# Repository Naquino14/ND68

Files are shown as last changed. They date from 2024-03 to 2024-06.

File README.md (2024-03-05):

# ND68
**ND68 MKL (Most keyless) Proto**
ND68 3
ND68 is a quest to design a custom 68% keyboard pcb powered by an RP2040, complete with per key RGB, hot-swappable keys, and a USB-C connector. 
We are in the prototyping phase, and if successful the prototype works as a macro pad. 
ND68 4

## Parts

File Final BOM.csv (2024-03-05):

# | QUANTITY | PART NUMBER | MANUFACTURER PART NUMBER | DESCRIPTION | CUSTOMER REFERENCE | BACKORDER | UNIT PRICE | EXTENDED PRICE
1 | 10 | 1276-1096-1-ND | CL21A106KOQNNNE | CAP CER 10UF 16V X5R 0805 |  | 0 | 0.07 | 0.7
2 | 10 | 490-13339-1-ND | GRM155R70J105KA12J | CAP CER 1UF 6.3V X7R 0402 |  | 0 | 0.035 | 0.35
3 | 50 | 1276-1013-1-ND | CL03A104KQ3NNNC | CAP CER 0.1UF 6.3V X5R 0201 |  | 0 | 0.008 | 0.4
4 | 10 | 490-9658-1-ND | GRM0335C1E150JA01D | CAP CER 15PF 25V C0G/NP0 0201 |  | 0 | 0.011 | 0.11
5 | 142 | 4878-1N4148WCT-ND | 1N4148W | DIODE GEN PURP 75V 150MA SOD123F |  | 0 | 0.0378 | 5.37
6 | 3 | 2073-USB4105-GF-ACT-ND | USB4105-GF-A | CONN RCP USB2.0 TYP C 24P SMD RA |  | 0 | 0.81 | 2.43
7 | 10 | 311-5.10KHRCT-ND | RC0603FR-075K1L | RES 5.1K OHM 1% 1/10W 0603 |  | 0 | 0.019 | 0.19
8 | 10 | 311-1.0KJRCT-ND | RC0402JR-071KL | RES 1K OHM 5% 1/16W 0402 |  | 0 | 0.018 | 0.18
9 | 10 | YAG3085CT-ND | RC0402FR-0727R4L | RES 27.4 OHM 1% 1/16W 0402 |  | 0 | 0.015 | 0.15
10 | 3 | CKN12310-1-ND | PTS636 SM43 SMTR LFS | SWITCH TACTILE SPST-NO 0.05A 12V |  | 0 | 0.19 | 0.57
11 | 3 | 488-NCP1117IST33T3GCT-ND | NCP1117IST33T3G | LDO REGULATOR, 1 A, FIXED AND AD |  | 0 | 0.62 | 1.86
12 | 3 | 2648-SC0914(13)CT-ND | SC0914(13) | IC MCU 32B EXT MEM 56QFN RP2040 |  | 0 | 0.7 | 2.1
13 | 3 | W25Q128JVSIQ-ND | W25Q128JVSIQ | IC FLASH 128MBIT SPI/QUAD 8SOIC |  | 0 | 1.73 | 5.19
14 | 3 | 535-9826-1-ND | ABM8-12.000MHZ-B2-T | CRYSTAL 12.0000MHZ 18PF SMD |  | 0 | 0.55 | 1.65
15 | 1 | PEC11R-4215F-S0024-ND | PEC11R-4215F-S0024 | ROTARY ENCODER MECHANICAL 24PPR |  | 0 | 2.12 | 2.12

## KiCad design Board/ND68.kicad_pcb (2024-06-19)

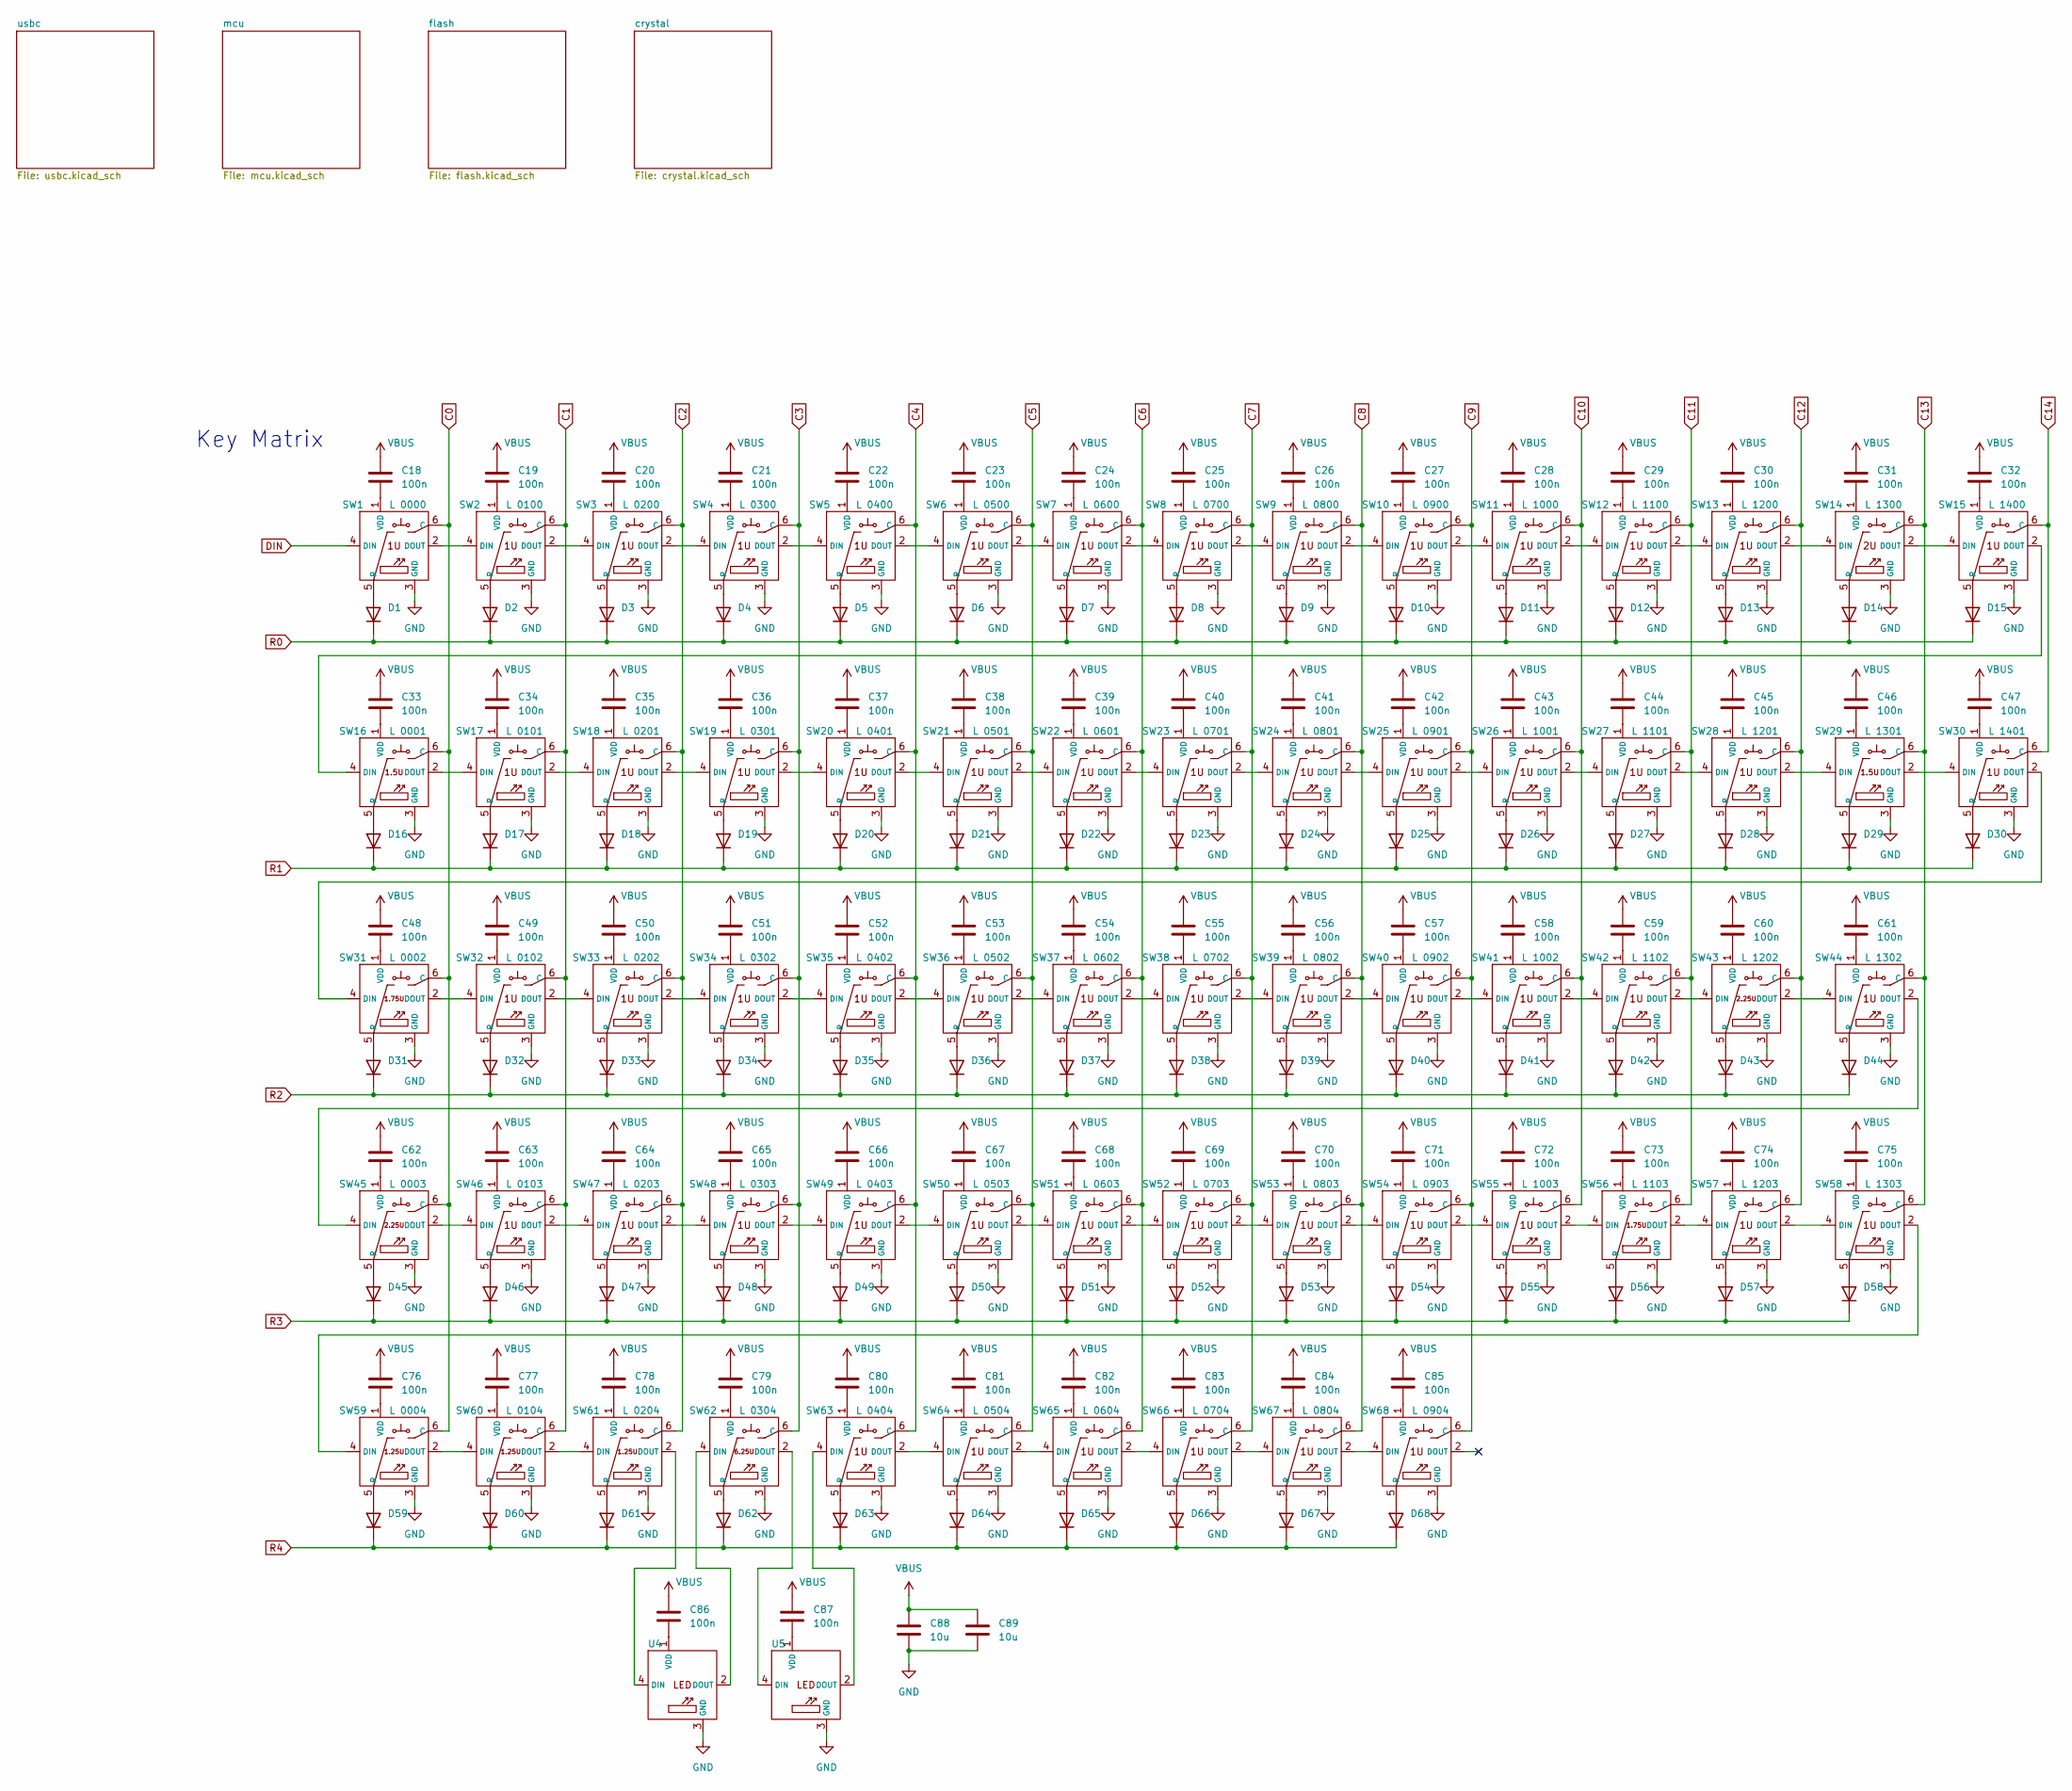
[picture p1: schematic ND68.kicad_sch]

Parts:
C18, C19, C20, C21, C22, C23, C24, C25, C26, C27, C28, C29, C30, C31, C32, C33, C34, C35, C36, C37, C38, C39, C40, C41, C42, C43, C44, C45, C46, C47, C48, C49, C50, C51, C52, C53, C54, C55, C56, C57, C58, C59, C60, C61, C62, C63, C64, C65, C66, C67, C68, C69, C70, C71, C72, C73, C74, C75, C76, C77, C78, C79, C80, C81, C82, C83, C84, C85, C86, C87: 100n; C_0603_1608Metric; DigiKey 311-1088-2-ND
C88, C89: 10u; C_0805_2012Metric; DigiKey 1276-1096-1-ND
D1, D2, D3, D4, D5, D6, D7, D8, D9, D10, D11, D12, D13, D14, D15, D16, D17, D18, D19, D20, D21, D22, D23, D24, D25, D26, D27, D28, D29, D30, D31, D32, D33, D34, D35, D36, D37, D38, D39, D40, D41, D42, D43, D44, D45, D46, D47, D48, D49, D50, D51, D52, D53, D54, D55, D56, D57, D58, D59, D60, D61, D62, D63, D64, D65, D66, D67, D68: D; D_SOD-123F; DigiKey 4878-1N4148WCT-ND
SW1, SW2, SW3, SW4, SW5, SW6, SW7, SW8, SW9, SW10, SW11, SW12, SW13, SW15, SW17, SW18, SW19, SW20, SW21, SW22, SW23, SW24, SW25, SW26, SW27, SW28, SW30, SW32, SW33, SW34, SW35, SW36, SW37, SW38, SW39, SW40, SW41, SW42, SW44, SW46, SW47, SW48, SW49, SW50, SW51, SW52, SW53, SW54, SW55, SW57, SW58, SW63, SW64, SW65, SW66, SW67, SW68: ND68-1U-HS-ARGB
SW14: ND68-2U-HS-ARGB
SW16, SW29: ND68-1.5U-HS-ARGB
SW31, SW56: ND68-1.75U-HS-ARGB
SW43, SW45: ND68-2.25U-HS-ARGB
SW59, SW60, SW61: ND68-1.25U-HS-ARGB
SW62: ND68-6.25U-HS-ARGB
U4, U5: ND68-1U-ARGB_LED_ONLY

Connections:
C0: SW1.6 (C), SW16.6 (C), SW31.6 (C), SW45.6 (C), SW59.6 (C)
C1: SW2.6 (C), SW17.6 (C), SW32.6 (C), SW46.6 (C), SW60.6 (C)
C2: SW3.6 (C), SW18.6 (C), SW33.6 (C), SW47.6 (C), SW61.6 (C)
C3: SW4.6 (C), SW19.6 (C), SW34.6 (C), SW48.6 (C), SW62.6 (C)
C4: SW5.6 (C), SW20.6 (C), SW35.6 (C), SW49.6 (C), SW63.6 (C)
C5: SW6.6 (C), SW21.6 (C), SW36.6 (C), SW50.6 (C), SW64.6 (C)
C6: SW7.6 (C), SW22.6 (C), SW37.6 (C), SW51.6 (C), SW65.6 (C)
C7: SW8.6 (C), SW23.6 (C), SW38.6 (C), SW52.6 (C), SW66.6 (C)
C8: SW9.6 (C), SW24.6 (C), SW39.6 (C), SW53.6 (C), SW67.6 (C)
C9: SW10.6 (C), SW25.6 (C), SW40.6 (C), SW54.6 (C), SW68.6 (C)
C10: SW11.6 (C), SW26.6 (C), SW41.6 (C), SW55.6 (C)
C11: SW12.6 (C), SW27.6 (C), SW42.6 (C), SW56.6 (C)
C12: SW13.6 (C), SW28.6 (C), SW43.6 (C), SW57.6 (C)
C13: SW14.6 (C), SW29.6 (C), SW44.6 (C), SW58.6 (C)
C14: SW15.6 (C), SW30.6 (C)
DIN: SW1.4 (DIN); also elsewhere on the board
GND: C88.2, C89.2, SW1.3 (GND), SW2.3 (GND), SW3.3 (GND), SW4.3 (GND), SW5.3 (GND), SW6.3 (GND), SW7.3 (GND), SW8.3 (GND), SW9.3 (GND), SW10.3 (GND), SW11.3 (GND), SW12.3 (GND), SW13.3 (GND), SW14.3 (GND), SW15.3 (GND), SW16.3 (GND), SW17.3 (GND), SW18.3 (GND), SW19.3 (GND), SW20.3 (GND), SW21.3 (GND), SW22.3 (GND), SW23.3 (GND), SW24.3 (GND), SW25.3 (GND), SW26.3 (GND), SW27.3 (GND), SW28.3 (GND), SW29.3 (GND), SW30.3 (GND), SW31.3 (GND), SW32.3 (GND), SW33.3 (GND), SW34.3 (GND), SW35.3 (GND), SW36.3 (GND), SW37.3 (GND), SW38.3 (GND), SW39.3 (GND), SW40.3 (GND), SW41.3 (GND), SW42.3 (GND), SW43.3 (GND), SW44.3 (GND), SW45.3 (GND), SW46.3 (GND), SW47.3 (GND), SW48.3 (GND), SW49.3 (GND), SW50.3 (GND), SW51.3 (GND), SW52.3 (GND), SW53.3 (GND), SW54.3 (GND), SW55.3 (GND), SW56.3 (GND), SW57.3 (GND), SW58.3 (GND), SW59.3 (GND), SW60.3 (GND), SW61.3 (GND), SW62.3 (GND), SW63.3 (GND), SW64.3 (GND), SW65.3 (GND), SW66.3 (GND), SW67.3 (GND), SW68.3 (GND), U4.3 (GND), U5.3 (GND); also elsewhere on the board
unnamed: D1.2 (A), SW1.5 (R)
unnamed: D2.2 (A), SW2.5 (R)
unnamed: D3.2 (A), SW3.5 (R)
unnamed: D4.2 (A), SW4.5 (R)
unnamed: D5.2 (A), SW5.5 (R)
unnamed: D6.2 (A), SW6.5 (R)
unnamed: D7.2 (A), SW7.5 (R)
unnamed: D8.2 (A), SW8.5 (R)
unnamed: D9.2 (A), SW9.5 (R)
unnamed: D10.2 (A), SW10.5 (R)
unnamed: D11.2 (A), SW11.5 (R)
unnamed: D12.2 (A), SW12.5 (R)
unnamed: D13.2 (A), SW13.5 (R)
unnamed: D14.2 (A), SW14.5 (R)
unnamed: D15.2 (A), SW15.5 (R)
unnamed: D16.2 (A), SW16.5 (R)
unnamed: D17.2 (A), SW17.5 (R)
unnamed: D18.2 (A), SW18.5 (R)
unnamed: D19.2 (A), SW19.5 (R)
unnamed: D20.2 (A), SW20.5 (R)
unnamed: D21.2 (A), SW21.5 (R)
unnamed: D22.2 (A), SW22.5 (R)
unnamed: D23.2 (A), SW23.5 (R)
unnamed: D24.2 (A), SW24.5 (R)
unnamed: D25.2 (A), SW25.5 (R)
unnamed: D26.2 (A), SW26.5 (R)
unnamed: D27.2 (A), SW27.5 (R)
unnamed: D28.2 (A), SW28.5 (R)
unnamed: D29.2 (A), SW29.5 (R)
unnamed: D30.2 (A), SW30.5 (R)
unnamed: D31.2 (A), SW31.5 (R)
unnamed: D32.2 (A), SW32.5 (R)
unnamed: D33.2 (A), SW33.5 (R)
unnamed: D34.2 (A), SW34.5 (R)
unnamed: D35.2 (A), SW35.5 (R)
unnamed: D36.2 (A), SW36.5 (R)
unnamed: D37.2 (A), SW37.5 (R)
unnamed: D38.2 (A), SW38.5 (R)
unnamed: D39.2 (A), SW39.5 (R)
unnamed: D40.2 (A), SW40.5 (R)
unnamed: D41.2 (A), SW41.5 (R)
unnamed: D42.2 (A), SW42.5 (R)
unnamed: D43.2 (A), SW43.5 (R)
unnamed: D44.2 (A), SW44.5 (R)
unnamed: D45.2 (A), SW45.5 (R)
unnamed: D46.2 (A), SW46.5 (R)
unnamed: D47.2 (A), SW47.5 (R)
unnamed: D48.2 (A), SW48.5 (R)
unnamed: D49.2 (A), SW49.5 (R)
unnamed: D50.2 (A), SW50.5 (R)
unnamed: D51.2 (A), SW51.5 (R)
unnamed: D52.2 (A), SW52.5 (R)
unnamed: D53.2 (A), SW53.5 (R)
unnamed: D54.2 (A), SW54.5 (R)
unnamed: D55.2 (A), SW55.5 (R)
unnamed: D56.2 (A), SW56.5 (R)
unnamed: D57.2 (A), SW57.5 (R)
unnamed: D58.2 (A), SW58.5 (R)
unnamed: D59.2 (A), SW59.5 (R)
unnamed: D60.2 (A), SW60.5 (R)
unnamed: D61.2 (A), SW61.5 (R)
unnamed: D62.2 (A), SW62.5 (R)
unnamed: D63.2 (A), SW63.5 (R)
unnamed: D64.2 (A), SW64.5 (R)
unnamed: D65.2 (A), SW65.5 (R)
unnamed: D66.2 (A), SW66.5 (R)
unnamed: D67.2 (A), SW67.5 (R)
unnamed: D68.2 (A), SW68.5 (R)
unnamed: SW1.2 (DOUT), SW2.4 (DIN)
unnamed: C18.2, SW1.1 (VDD)
unnamed: SW2.2 (DOUT), SW3.4 (DIN)
unnamed: C19.2, SW2.1 (VDD)
unnamed: SW3.2 (DOUT), SW4.4 (DIN)
unnamed: C20.2, SW3.1 (VDD)
unnamed: SW4.2 (DOUT), SW5.4 (DIN)
unnamed: C21.2, SW4.1 (VDD)
unnamed: SW5.2 (DOUT), SW6.4 (DIN)
unnamed: C22.2, SW5.1 (VDD)
unnamed: SW6.2 (DOUT), SW7.4 (DIN)
unnamed: C23.2, SW6.1 (VDD)
unnamed: SW7.2 (DOUT), SW8.4 (DIN)
unnamed: C24.2, SW7.1 (VDD)
unnamed: SW8.2 (DOUT), SW9.4 (DIN)
unnamed: C25.2, SW8.1 (VDD)
unnamed: C26.2, SW9.1 (VDD)
unnamed: SW9.2 (DOUT), SW10.4 (DIN)
unnamed: SW10.2 (DOUT), SW11.4 (DIN)
unnamed: C27.2, SW10.1 (VDD)
unnamed: SW11.2 (DOUT), SW12.4 (DIN)
unnamed: C28.2, SW11.1 (VDD)
unnamed: SW12.2 (DOUT), SW13.4 (DIN)
unnamed: C29.2, SW12.1 (VDD)
unnamed: SW13.2 (DOUT), SW14.4 (DIN)
unnamed: C30.2, SW13.1 (VDD)
unnamed: SW14.2 (DOUT), SW15.4 (DIN)
unnamed: C31.2, SW14.1 (VDD)
unnamed: SW15.2 (DOUT), SW16.4 (DIN)
unnamed: C32.2, SW15.1 (VDD)
unnamed: SW16.2 (DOUT), SW17.4 (DIN)
unnamed: C33.2, SW16.1 (VDD)
unnamed: SW17.2 (DOUT), SW18.4 (DIN)
unnamed: C34.2, SW17.1 (VDD)
unnamed: SW18.2 (DOUT), SW19.4 (DIN)
unnamed: C35.2, SW18.1 (VDD)
unnamed: SW19.2 (DOUT), SW20.4 (DIN)
unnamed: C36.2, SW19.1 (VDD)
unnamed: SW20.2 (DOUT), SW21.4 (DIN)
unnamed: C37.2, SW20.1 (VDD)
unnamed: SW21.2 (DOUT), SW22.4 (DIN)
unnamed: C38.2, SW21.1 (VDD)
unnamed: SW22.2 (DOUT), SW23.4 (DIN)
unnamed: C39.2, SW22.1 (VDD)
unnamed: SW23.2 (DOUT), SW24.4 (DIN)
unnamed: C40.2, SW23.1 (VDD)
unnamed: SW24.2 (DOUT), SW25.4 (DIN)
unnamed: C41.2, SW24.1 (VDD)
unnamed: SW25.2 (DOUT), SW26.4 (DIN)
unnamed: C42.2, SW25.1 (VDD)
unnamed: SW26.2 (DOUT), SW27.4 (DIN)
unnamed: C43.2, SW26.1 (VDD)
unnamed: SW27.2 (DOUT), SW28.4 (DIN)
unnamed: C44.2, SW27.1 (VDD)
unnamed: SW28.2 (DOUT), SW29.4 (DIN)
unnamed: C45.2, SW28.1 (VDD)
unnamed: SW29.2 (DOUT), SW30.4 (DIN)
unnamed: C46.2, SW29.1 (VDD)
unnamed: SW30.2 (DOUT), SW31.4 (DIN)
unnamed: C47.2, SW30.1 (VDD)
unnamed: SW31.2 (DOUT), SW32.4 (DIN)
unnamed: C48.2, SW31.1 (VDD)
unnamed: SW32.2 (DOUT), SW33.4 (DIN)
unnamed: C49.2, SW32.1 (VDD)
unnamed: SW33.2 (DOUT), SW34.4 (DIN)
unnamed: C50.2, SW33.1 (VDD)
unnamed: SW34.2 (DOUT), SW35.4 (DIN)
unnamed: C51.2, SW34.1 (VDD)
unnamed: SW35.2 (DOUT), SW36.4 (DIN)
unnamed: C52.2, SW35.1 (VDD)
unnamed: SW36.2 (DOUT), SW37.4 (DIN)
unnamed: C53.2, SW36.1 (VDD)
unnamed: SW37.2 (DOUT), SW38.4 (DIN)
unnamed: C54.2, SW37.1 (VDD)
unnamed: SW38.2 (DOUT), SW39.4 (DIN)
unnamed: C55.2, SW38.1 (VDD)
unnamed: SW39.2 (DOUT), SW40.4 (DIN)
unnamed: C56.2, SW39.1 (VDD)
unnamed: SW40.2 (DOUT), SW41.4 (DIN)
unnamed: C57.2, SW40.1 (VDD)
unnamed: SW41.2 (DOUT), SW42.4 (DIN)
unnamed: C58.2, SW41.1 (VDD)
unnamed: SW42.2 (DOUT), SW43.4 (DIN)
unnamed: C59.2, SW42.1 (VDD)
unnamed: SW43.2 (DOUT), SW44.4 (DIN)
unnamed: C60.2, SW43.1 (VDD)
unnamed: SW44.2 (DOUT), SW45.4 (DIN)
unnamed: C61.2, SW44.1 (VDD)
unnamed: SW45.2 (DOUT), SW46.4 (DIN)
unnamed: C62.2, SW45.1 (VDD)
unnamed: SW46.2 (DOUT), SW47.4 (DIN)
unnamed: C63.2, SW46.1 (VDD)
unnamed: SW47.2 (DOUT), SW48.4 (DIN)
unnamed: C64.2, SW47.1 (VDD)
unnamed: SW48.2 (DOUT), SW49.4 (DIN)
unnamed: C65.2, SW48.1 (VDD)
unnamed: SW49.2 (DOUT), SW50.4 (DIN)
unnamed: C66.2, SW49.1 (VDD)
unnamed: SW50.2 (DOUT), SW51.4 (DIN)
unnamed: C67.2, SW50.1 (VDD)
unnamed: SW51.2 (DOUT), SW52.4 (DIN)
unnamed: C68.2, SW51.1 (VDD)
unnamed: SW52.2 (DOUT), SW53.4 (DIN)
unnamed: C69.2, SW52.1 (VDD)
unnamed: SW53.2 (DOUT), SW54.4 (DIN)
unnamed: C70.2, SW53.1 (VDD)
unnamed: SW54.2 (DOUT), SW55.4 (DIN)
unnamed: C71.2, SW54.1 (VDD)
unnamed: SW55.2 (DOUT), SW56.4 (DIN)
unnamed: C72.2, SW55.1 (VDD)
unnamed: SW56.2 (DOUT), SW57.4 (DIN)
unnamed: C73.2, SW56.1 (VDD)
unnamed: SW57.2 (DOUT), SW58.4 (DIN)
unnamed: C74.2, SW57.1 (VDD)
unnamed: SW58.2 (DOUT), SW59.4 (DIN)
unnamed: C75.2, SW58.1 (VDD)
unnamed: SW59.2 (DOUT), SW60.4 (DIN)
unnamed: C76.2, SW59.1 (VDD)
unnamed: SW60.2 (DOUT), SW61.4 (DIN)
unnamed: C77.2, SW60.1 (VDD)
unnamed: SW61.2 (DOUT), U4.4 (DIN)
unnamed: C78.2, SW61.1 (VDD)
unnamed: SW62.4 (DIN), U4.2 (DOUT)
unnamed: SW62.2 (DOUT), U5.4 (DIN)
unnamed: C79.2, SW62.1 (VDD)
unnamed: SW63.4 (DIN), U5.2 (DOUT)
unnamed: SW63.2 (DOUT), SW64.4 (DIN)
unnamed: C80.2, SW63.1 (VDD)
unnamed: SW64.2 (DOUT), SW65.4 (DIN)
unnamed: C81.2, SW64.1 (VDD)
unnamed: SW65.2 (DOUT), SW66.4 (DIN)
unnamed: C82.2, SW65.1 (VDD)
unnamed: SW66.2 (DOUT), SW67.4 (DIN)
unnamed: C83.2, SW66.1 (VDD)
unnamed: SW67.2 (DOUT), SW68.4 (DIN)
unnamed: C84.2, SW67.1 (VDD)
unnamed: C85.2, SW68.1 (VDD)
unnamed: C86.2, U4.1 (VDD)
unnamed: C87.2, U5.1 (VDD)
R0: D1.1 (K), D2.1 (K), D3.1 (K), D4.1 (K), D5.1 (K), D6.1 (K), D7.1 (K), D8.1 (K), D9.1 (K), D10.1 (K), D11.1 (K), D12.1 (K), D13.1 (K), D14.1 (K), D15.1 (K)
R1: D16.1 (K), D17.1 (K), D18.1 (K), D19.1 (K), D20.1 (K), D21.1 (K), D22.1 (K), D23.1 (K), D24.1 (K), D25.1 (K), D26.1 (K), D27.1 (K), D28.1 (K), D29.1 (K), D30.1 (K)
R2: D31.1 (K), D32.1 (K), D33.1 (K), D34.1 (K), D35.1 (K), D36.1 (K), D37.1 (K), D38.1 (K), D39.1 (K), D40.1 (K), D41.1 (K), D42.1 (K), D43.1 (K), D44.1 (K)
R3: D45.1 (K), D46.1 (K), D47.1 (K), D48.1 (K), D49.1 (K), D50.1 (K), D51.1 (K), D52.1 (K), D53.1 (K), D54.1 (K), D55.1 (K), D56.1 (K), D57.1 (K), D58.1 (K)
R4: D59.1 (K), D60.1 (K), D61.1 (K), D62.1 (K), D63.1 (K), D64.1 (K), D65.1 (K), D66.1 (K), D67.1 (K), D68.1 (K)
VBUS: C18.1, C19.1, C20.1, C21.1, C22.1, C23.1, C24.1, C25.1, C26.1, C27.1, C28.1, C29.1, C30.1, C31.1, C32.1, C33.1, C34.1, C35.1, C36.1, C37.1, C38.1, C39.1, C40.1, C41.1, C42.1, C43.1, C44.1, C45.1, C46.1, C47.1, C48.1, C49.1, C50.1, C51.1, C52.1, C53.1, C54.1, C55.1, C56.1, C57.1, C58.1, C59.1, C60.1, C61.1, C62.1, C63.1, C64.1, C65.1, C66.1, C67.1, C68.1, C69.1, C70.1, C71.1, C72.1, C73.1, C74.1, C75.1, C76.1, C77.1, C78.1, C79.1, C80.1, C81.1, C82.1, C83.1, C84.1, C85.1, C86.1, C87.1, C88.1, C89.1; also elsewhere on the board

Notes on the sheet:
Key Matrix

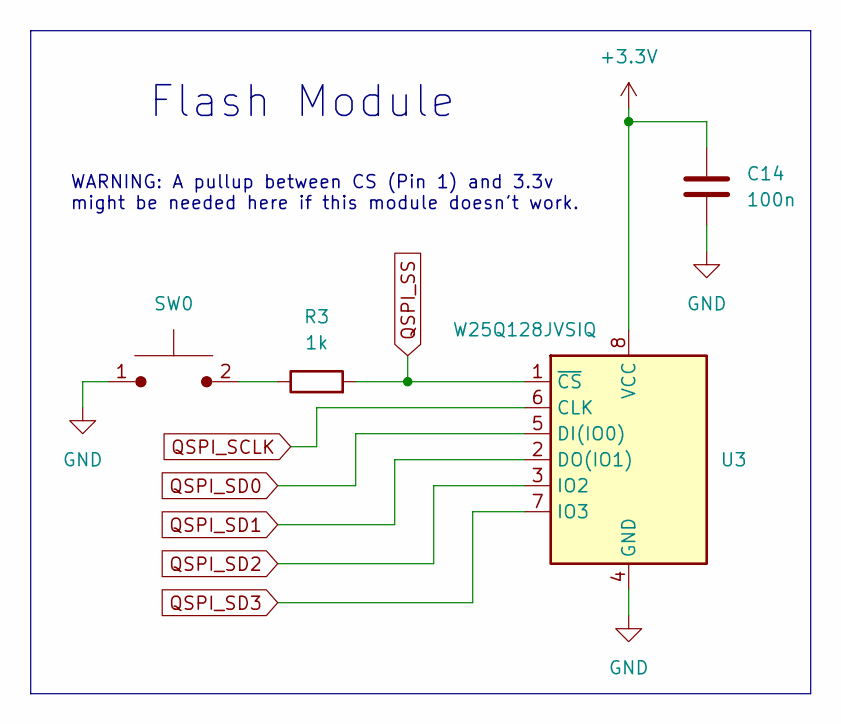
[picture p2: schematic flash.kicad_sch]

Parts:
C14: 100n; C_0201_0603Metric; DigiKey 1276-1013-1-ND
R3: 1k; R_0402_1005Metric; DigiKey 311-1.0KJRCT-ND
SW0: PTS636 SM43 SMTR LFS; DigiKey CKN12310-1-ND
U3: W25Q128JVSIQ; DigiKey W25Q128JVSIQ-ND

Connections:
+3.3V: C14.1, U3.8 (VCC); also elsewhere on the board
GND: C14.2, SW0.1, U3.4 (GND); also elsewhere on the board
unnamed: R3.1, SW0.2
QSPI_SCLK: U3.6 (CLK); also elsewhere on the board
QSPI_SD0: U3.5 (DI(IO0)); also elsewhere on the board
QSPI_SD1: U3.2 (DO(IO1)); also elsewhere on the board
QSPI_SD2: U3.3 (IO2); also elsewhere on the board
QSPI_SD3: U3.7 (IO3); also elsewhere on the board
QSPI_SS: R3.2, U3.1 (~CS); also elsewhere on the board

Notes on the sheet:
Flash Module
WARNING: A pullup between CS (Pin 1) and 3.3v might be needed here if this module doesn't work.

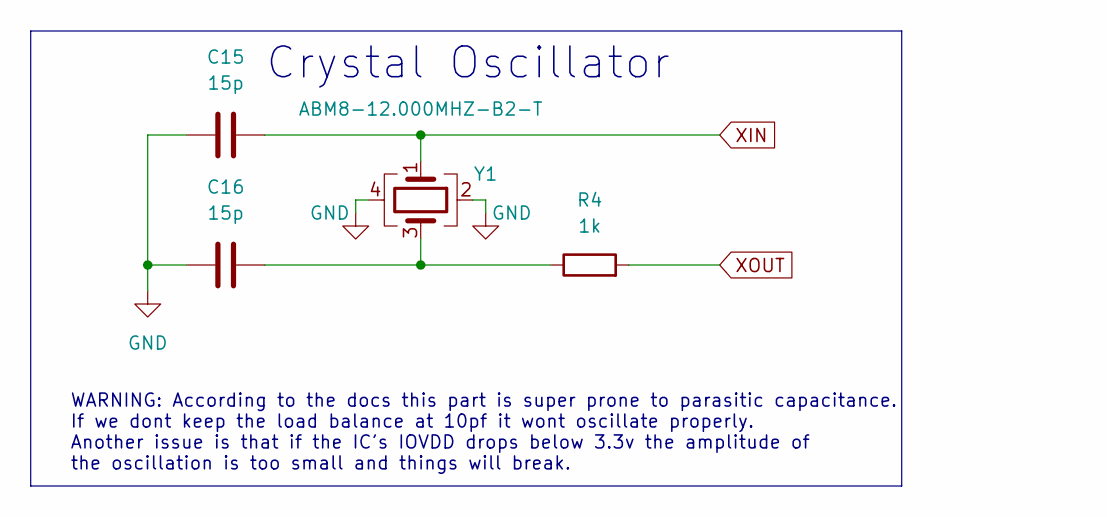
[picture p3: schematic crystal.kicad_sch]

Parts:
C15, C16: 15p; C_0201_0603Metric; DigiKey 490-9658-1-ND
R4: 1k; R_0402_1005Metric; DigiKey 311-1.0KJRCT-ND
Y1: Crystal_GND24; XTAL_ABM8-12.000MHZ-B2-T; DigiKey 535-9826-1-ND

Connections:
GND: C15.1, C16.1, Y1.2, Y1.4; also elsewhere on the board
unnamed: C16.2, R4.1, Y1.3
XIN: C15.2, Y1.1; also elsewhere on the board
XOUT: R4.2; also elsewhere on the board

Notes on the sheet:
WARNING: According to the docs this part is super prone to parasitic capacitance. If we dont keep the load balance at 10pf it wont oscillate properly. Another issue is that if the IC's IOVDD drops below 3.3v the amplitude of the oscillation is too small and things will break.
Crystal Oscillator

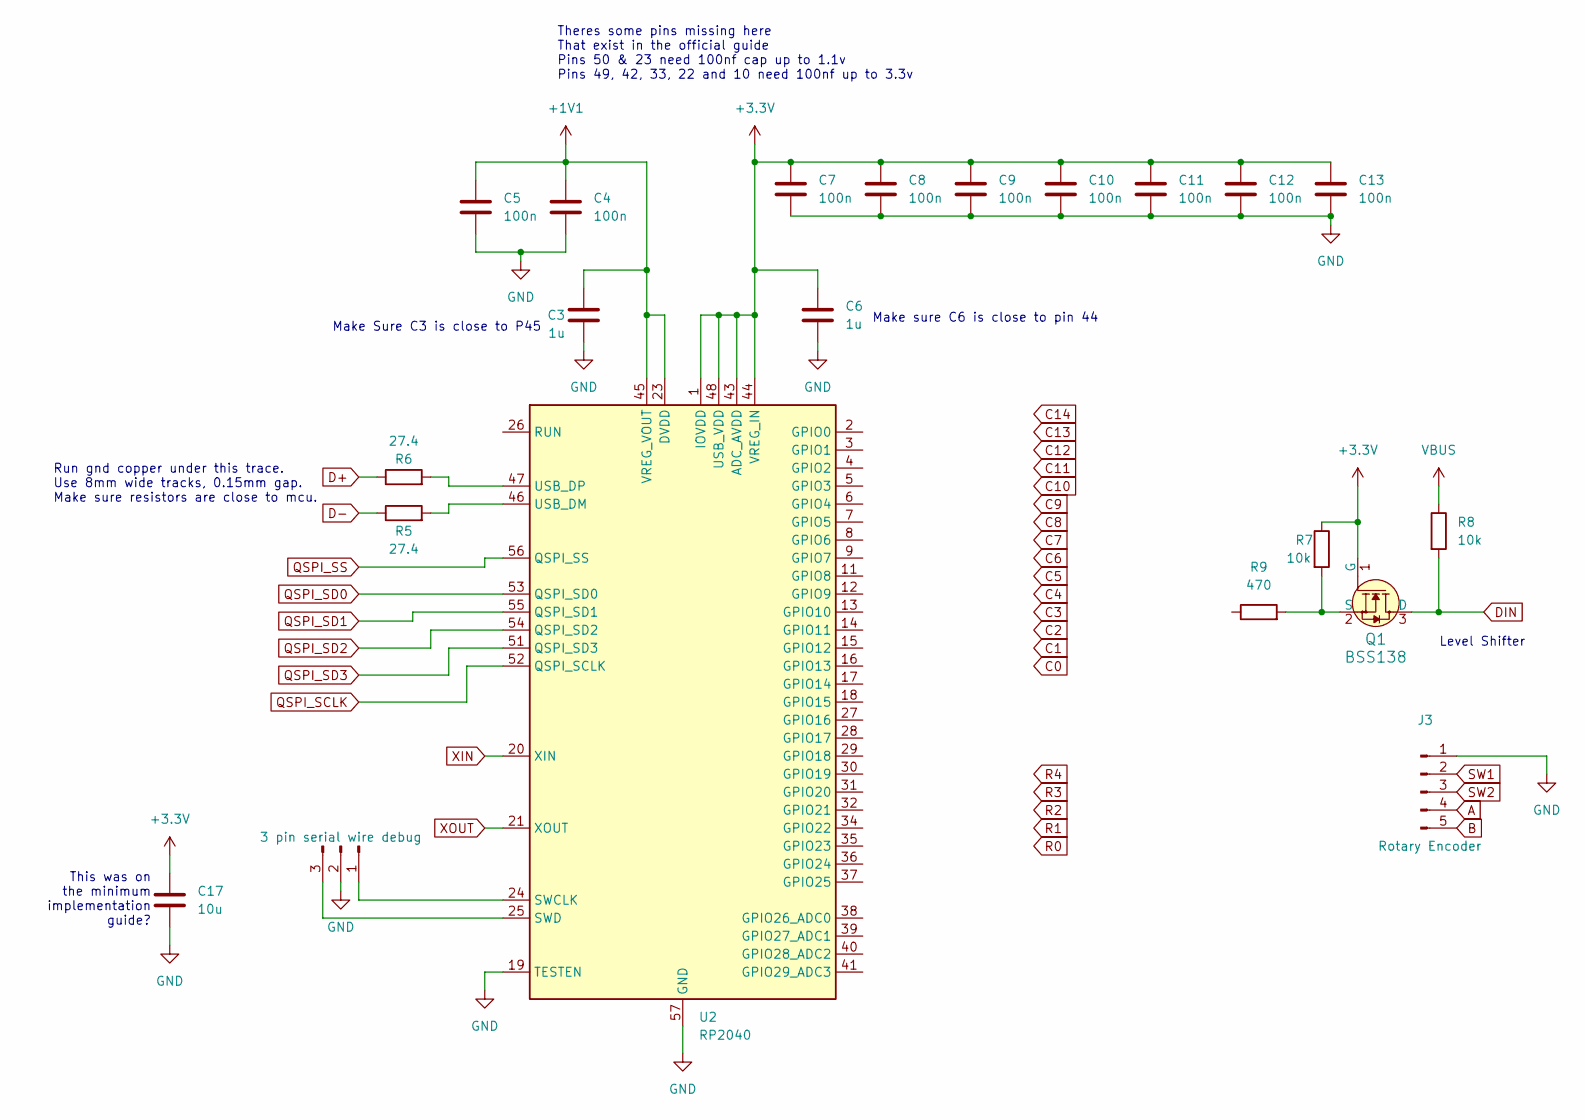
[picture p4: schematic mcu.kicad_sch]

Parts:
C3, C6: 1u; C_0402_1005Metric; DigiKey 490-13339-1-ND
C4, C5, C7, C8, C9, C10, C11, C12, C13: 100n; C_0201_0603Metric; DigiKey 1276-1013-1-ND
C17: 10u; C_0805_2012Metric; DigiKey 1276-1096-1-ND
J2: Conn_01x03_Pin; PinHeader_1x03_P2.54mm_Vertical
J3: Conn_01x05_Pin; PinHeader_1x05_P2.54mm_Vertical
Q1: BSS138; SOT-23-3; MPN BSS138; Digi-Key_PN BSS138CT-ND
R5, R6: 27.4; R_0402_1005Metric; DigiKey YAG3085CT-ND
R7, R8: 10k; R_0402_1005Metric; DigiKey 311-10KJRTR-ND
R9: 470; R_0603_1608Metric; DigiKey P470DBTR-ND
U2: RP2040; QFN-56-1EP_7x7mm_P0.4mm_EP3.2x3.2mm

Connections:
+1V1: C3.1, C4.1, C5.1, U2.23 (DVDD), U2.45 (VREG_VOUT), U2.50 (DVDD)
+3.3V: C6.1, C7.1, C8.1, C9.1, C10.1, C11.1, C12.1, C13.1, C17.1, Q1.1 (G), R7.1, U2.1 (IOVDD), U2.10 (IOVDD), U2.22 (IOVDD), U2.33 (IOVDD), U2.42 (IOVDD), U2.43 (ADC_AVDD), U2.44 (VREG_IN), U2.48 (USB_VDD), U2.49 (IOVDD); also elsewhere on the board
A: J3.4
B: J3.5
D+: R6.1; also elsewhere on the board
D-: R5.1; also elsewhere on the board
DIN: Q1.3 (D), R8.2; also elsewhere on the board
GND: C3.2, C4.2, C5.2, C6.2, C7.2, C8.2, C9.2, C10.2, C11.2, C12.2, C13.2, C17.2, J2.2, J3.1, U2.19 (TESTEN), U2.57 (GND); also elsewhere on the board
unnamed: J2.1, U2.24 (SWCLK)
unnamed: J2.3, U2.25 (SWD)
unnamed: Q1.2 (S), R7.2, R9.2
unnamed: R5.2, U2.46 (USB_DM)
unnamed: R6.2, U2.47 (USB_DP)
QSPI_SCLK: U2.52 (QSPI_SCLK); also elsewhere on the board
QSPI_SD0: U2.53 (QSPI_SD0); also elsewhere on the board
QSPI_SD1: U2.55 (QSPI_SD1); also elsewhere on the board
QSPI_SD2: U2.54 (QSPI_SD2); also elsewhere on the board
QSPI_SD3: U2.51 (QSPI_SD3); also elsewhere on the board
QSPI_SS: U2.56 (QSPI_SS); also elsewhere on the board
SW1: J3.2
SW2: J3.3
VBUS: R8.1; also elsewhere on the board
XIN: U2.20 (XIN); also elsewhere on the board
XOUT: U2.21 (XOUT); also elsewhere on the board

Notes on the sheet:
Level Shifter
This was on the minimum implementation guide?
Make sure C6 is close to pin 44
Theres some pins missing here That exist in the official guide Pins 50 & 23 need 100nf cap up to 1.1v Pins 49, 42, 33, 22 and 10 need 100nf up to 3.3v
Run gnd copper under this trace. Use 8mm wide tracks, 0.15mm gap. Make sure resistors are close to mcu.
Make Sure C3 is close to P45

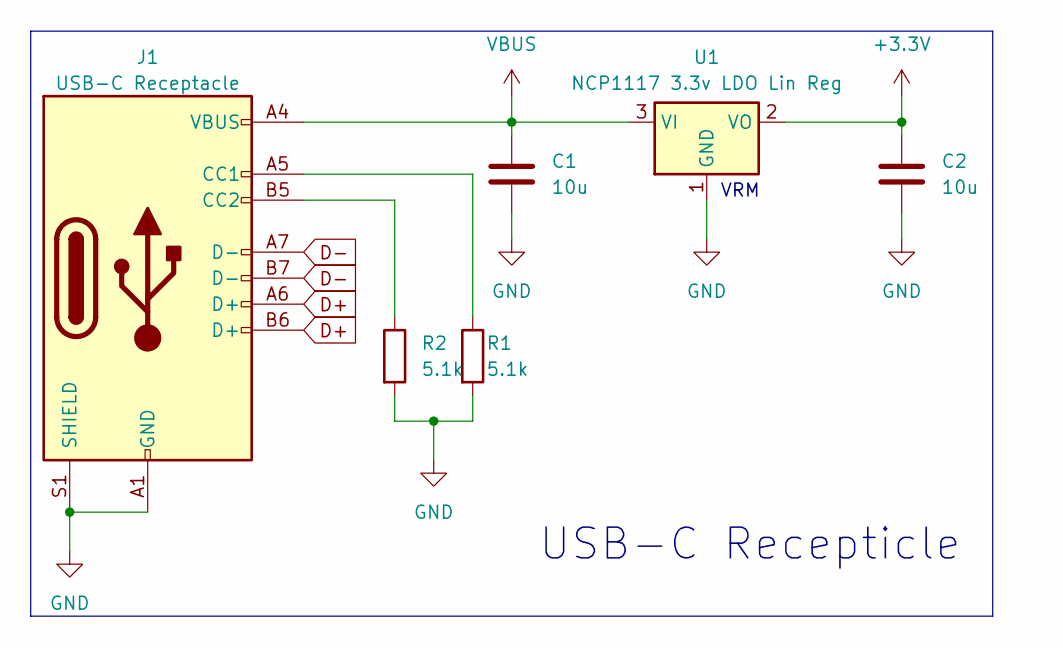
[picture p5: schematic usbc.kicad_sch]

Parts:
C1, C2: 10u; C_0805_2012Metric; DigiKey 1276-1096-1-ND
J1: USB_C_Receptacle_USB2.0_14P; USB_C_Receptacle_GCT_USB4105-GF-A; DigiKey 2073-USB4105-GF-ACT-ND
R1, R2: 5.1k; R_0603_1608Metric; DigiKey 311-5.10KHRCT-ND
U1: NCP1117-3.3_SOT223; SOT-223-3_TabPin2; DigiKey 488-NCP1117IST33T3GCT-ND

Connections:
+3.3V: C2.1, U1.2 (VO); also elsewhere on the board
D+: J1.A6 (D+), J1.B6 (D+); also elsewhere on the board
D-: J1.A7 (D-), J1.B7 (D-); also elsewhere on the board
GND: C1.2, C2.2, J1.A1 (GND), J1.A12 (GND), J1.B1 (GND), J1.B12 (GND), J1.S1 (SHIELD), R1.2, R2.2, U1.1 (GND); also elsewhere on the board
unnamed: J1.A5 (CC1), R1.1
unnamed: J1.B5 (CC2), R2.1
VBUS: C1.1, J1.A4 (VBUS), J1.A9 (VBUS), J1.B4 (VBUS), J1.B9 (VBUS), U1.3 (VI); also elsewhere on the board

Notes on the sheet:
VRM
USB-C Recepticle

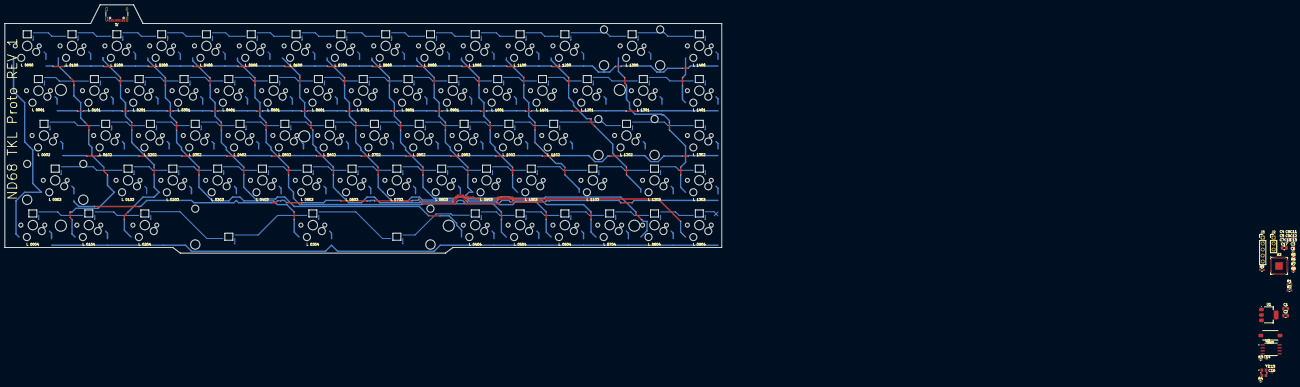
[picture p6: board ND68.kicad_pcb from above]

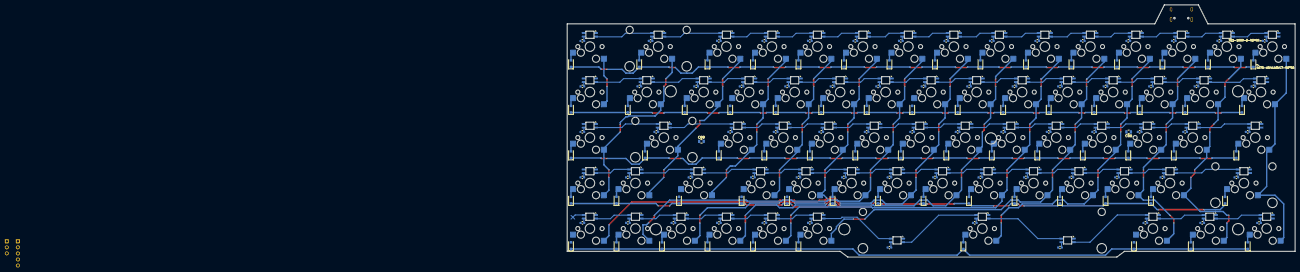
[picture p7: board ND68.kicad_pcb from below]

Board: 2 copper layers, 304.8 x 105.6 mm, 244 parts (140 on the bottom side), 251 nets.

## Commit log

2024-02-19 Create KiCad project
    [ND68.kicad_pcb, ND68.kicad_sch]
2024-02-19 Create board license
2024-02-19 Create board license readme
2024-02-20 Created drawing for Key and ARGB led and basic 4x4 proto wiring
    [ND68.kicad_sch]
2024-02-21 Added schematics, footprints, 3d models, and wiring to rp2040 input supply
    [ND68.kicad_sch, mcu.kicad_sch]
2024-02-21 Added pulldowns to USBC Receptacle CC1 and CC2 pins
    [mcu.kicad_sch]
2024-02-22 renamed mcu sheet to usbc
    [ND68.kicad_sch, usbc.kicad_sch]
2024-02-22 Added mcu power pin decoupling capacitors
    [ND68.kicad_sch, mcu.kicad_sch]
2024-02-22 Finished Flash Storage
    [flash.kicad_sch]
2024-02-22 Finished creating crystal oscillator
    [ND68.kicad_sch, crystal.kicad_sch]
2024-02-22 Update board folder readme to have precise language.
2024-02-22 Touch-up module schematics
    [crystal.kicad_sch, flash.kicad_sch, usbc.kicad_sch]
2024-02-23 Added the rest of the required stuff tp the mcu
    [ND68.kicad_sch, crystal.kicad_sch, flash.kicad_sch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]
2024-02-25 SK6812 rev mount led footprint
2024-02-27 Cleaned up key matrix and added diodes
    [ND68.kicad_sch]
2024-02-27 Added 3d model to ND68-1u-HS-ARGB and linked all parts to footprints
    [ND68.kicad_sch, usbc.kicad_sch]
2024-02-27 WIP PCB Layout
    [ND68.kicad_pcb, mcu.kicad_sch]
2024-02-29 VERY BASIC pcb layout
    [ND68.kicad_pcb, mcu.kicad_sch, usbc.kicad_sch]
2024-03-01 Fixed pad numbers on 1u argb hotswap footprint and added a border to the pcb :)
    [ND68.kicad_pcb, ND68.kicad_sch]
2024-03-01 Route mcu
    [ND68.kicad_pcb, ND68.kicad_sch, flash.kicad_sch]
2024-03-03 Done routing all parts.
    [ND68.kicad_pcb, ND68.kicad_sch, mcu.kicad_sch]
2024-03-05 Fixed coupling issues and cleaned up board
    [ND68.kicad_pcb]
2024-03-05 Ordered parts, upload BOM for 1 proto, 2 keyboards
    [Final BOM.csv, ND68.kicad_pcb]
2024-04-14 Rev 2
    [ND68.kicad_pcb, ND68.kicad_sch, mcu.kicad_sch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]
2024-04-29 MKL Rev 2 final
    [ND68.kicad_pcb]
2024-04-29 65% ke matrix
    [ND68.kicad_sch, crystal.kicad_sch, mcu.kicad_sch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]
2024-04-29 Added 2 leds
    [ND68.kicad_sch]
2024-04-30 Change led decoupler type
    [ND68.kicad_sch, mcu.kicad_sch]
2024-04-30 Starting from scratch
    [ND68.kicad_pcb, flash.kicad_sch]
2024-05-16 WIP Layout, all keys placed
    [ND68.kicad_sch]
2024-06-19 Finished PCB keyboard matrix & diodes
    [ND68.kicad_pcb]
2024-06-19 Wire capacitors and wire up diode matrix
    [ND68.kicad_pcb]
2024-07-21 Backing up"
    [flash.kicad_sch, mcu.kicad_sch]
2024-08-11 Finish routing key matrix
    [mcu.kicad_sch]
2024-08-11 Finish rev1
    [mcu.kicad_sch]
2024-08-11 Fix up board in accordance with JLCPCB DRC
2025-02-16 Rev 1 fix
    [ND68.kicad_sch]
